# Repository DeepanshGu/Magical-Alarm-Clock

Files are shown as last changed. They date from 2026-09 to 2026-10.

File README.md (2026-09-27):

clockfrontview


# Magical Alarm Clock

A custom-built alarm clock featuring an ST7789 display, XIAO ESP32-C3 microcontroller, 
4 physical buttons, and a buzzer — designed from scratch as part of Hack Club's 
[BLARE](https://blare.hackclub.com/) program.

Built entirely with KiCad (schematic + PCB), Fusion 360 (enclosure), and Arduino IDE (firmware).

## Features

- Real-time clock display on a 284x76 ST7789 TFT screen
- Set the current time manually using onboard buttons (fully offline — no WiFi/NTP required)
- Set, enable, and disable a daily alarm
- Buzzer sounds when the alarm triggers, silenced with a button press
- Fully custom 2-layer PCB — no breadboard or dev-kit shield required
- 3D-printable enclosure designed in Fusion 360

## Hardware

| Component | Notes |
|---|---|
| Seeed XIAO ESP32-C3 | Main microcontroller |
| ST7789 TFT Display | 284x76 resolution (unusual — not the standard 240x320) |
| 4x Push Buttons | Mode / Increment / Decrement / Alarm toggle |
| Buzzer | Alarm sound output |
| Custom PCB | 2-layer, designed in KiCad |

## Bill of Materials

| Part | Qty | Notes |
|---|---|---|
| Seeed XIAO ESP32-C3 | 1 | Main microcontroller |
| ST7789 TFT Display (284x76) | 1 | Non-standard resolution |
| Push Button Switch | 4 | Mode / Increment / Decrement / Alarm |
| Buzzer | 1 | Alarm sound |
| Custom PCB | 1 | See /gerber and drillfiles folder |
| M3 Heat-set Inserts | 4 | For top plate mounting |
| M3 Screws | 4 | Pairs with heat-set inserts |

## Repository Structure

## Building the PCB

1. Open the KiCad project files in the `/pcb` folder.
2. Gerber and drill files are included for direct upload to a fabrication service (e.g. JLCPCB).
3. Board is a standard 2-layer FR-4 PCB.
   clockpcb

## Firmware Setup

1. Install [Arduino IDE](https://www.arduino.cc/en/software).
2. Add ESP32 board support via Boards Manager.
3. Install these libraries via Library Manager:
   - `Adafruit ST7735 and ST7789`
   - `Adafruit GFX`
4. Open `/firmware/magical_alarm_clock.ino`.
5. Update the GPIO pin definitions at the top of the file to match your wiring.
6. Select **XIAO_ESP32C3** as the board, choose the correct COM port, and upload.

## Enclosure

The case was designed in Fusion 360 around the PCB and display's real dimensions, 
with support posts for heat-set inserts and a cutout for the display and buttons. 
STEP files are available in `/enclosure`.

## Credits

- Built following the [BLARE](https://blare.hackclub.com/) guide by Liam Newbill, part of Hack Club's Stardance program.
- Designed and built by [Deepansh Gupta](https://github.com/DeepanshGu).

## License

*No license added yet.*

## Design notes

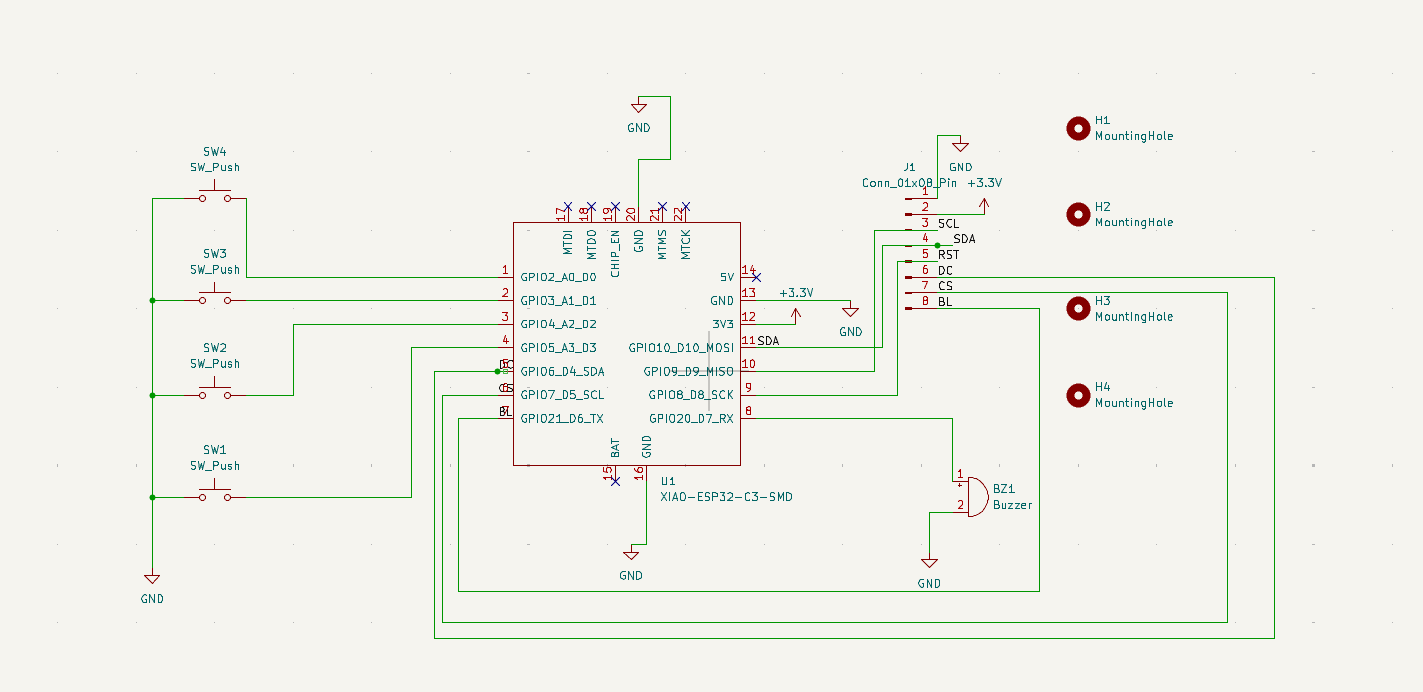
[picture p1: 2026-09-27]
images/clockschematic.png

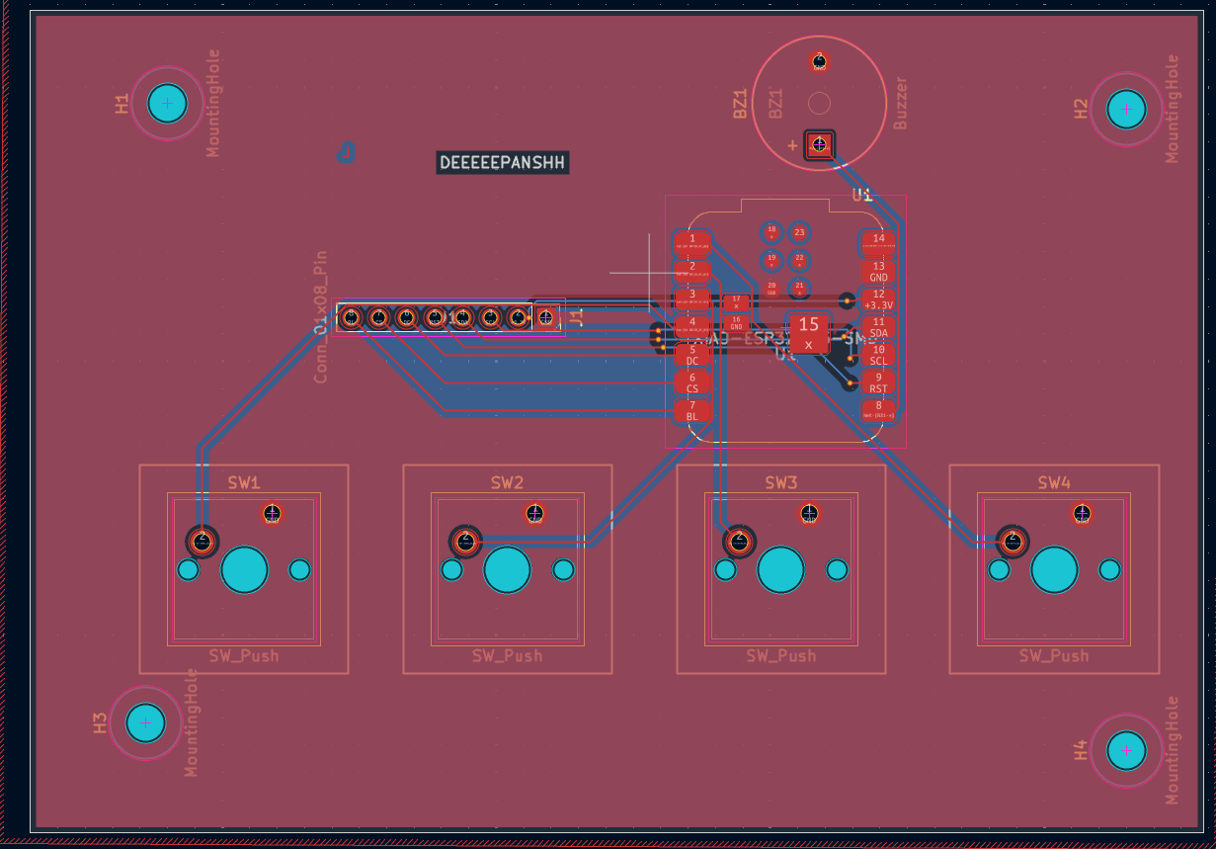
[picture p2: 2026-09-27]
images/clockpcb.png

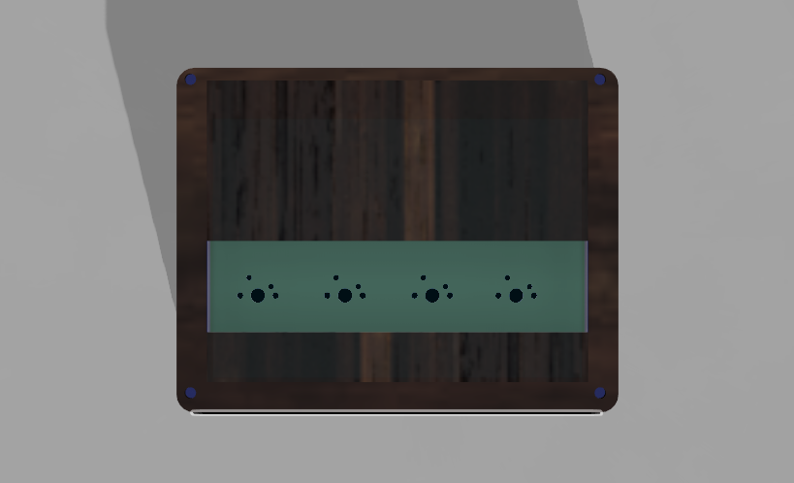
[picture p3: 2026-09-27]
images/clocktopview.png

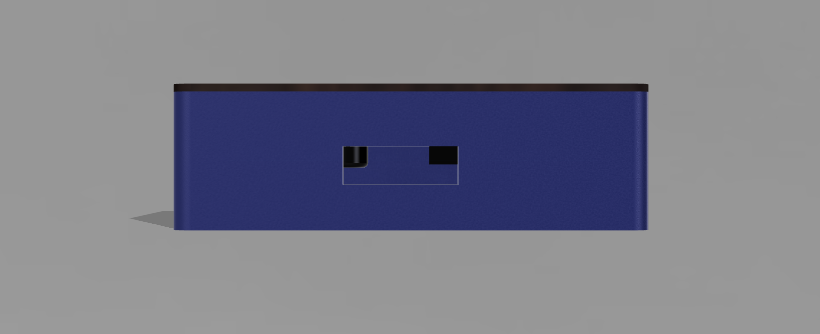
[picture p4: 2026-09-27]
images/clockbackview.png

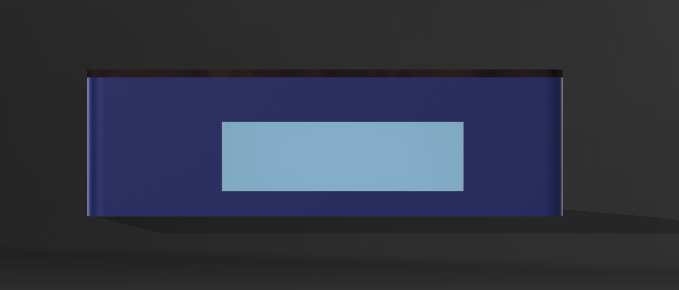
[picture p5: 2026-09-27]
images/clockfrontview.png

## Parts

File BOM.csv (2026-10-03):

Part | Qty | Unit Price (USD) | Link | Notes
Seeed XIAO ESP32-C3 | 1 | $5.49 | https://www.seeedstudio.com/Seeed-XIAO-ESP32C3-p-5431.html | Main microcontroller
2.25" TFT 76x284 SPI Display (ST7789P3) | 1 | $2.50 | https://www.buydisplay.com/chinese/2-25-inch-tft-serial-spi-76x284-lcd-display-module-w-st7789p3 | Non-standard resolution match
Tactile Push Button Switch 6x6mm (pack of 20) | 1 | $2.50 | https://www.adafruit.com/product/367 | Only 4 needed per clock; pack covers spares
5V Piezo Buzzer | 1 | $0.95 | https://www.adafruit.com/products/1536 | Breadboard-friendly; no driver circuit needed
M3 Brass Heat-Set Inserts (pack of 50) | 1 | $5.95 | https://www.adafruit.com/product/4256 | Only 4 needed per clock; pack covers spares
M3 Screws (6-8mm length) | 4 | ~$0.10 each |  | Widely available individually at any hardware/electronics store
Custom PCB | 1 | ~$8.20 (for 5 boards) | See /pcb/gerber-files.zip | JLCPCB quote for 2-layer 75x107mm board

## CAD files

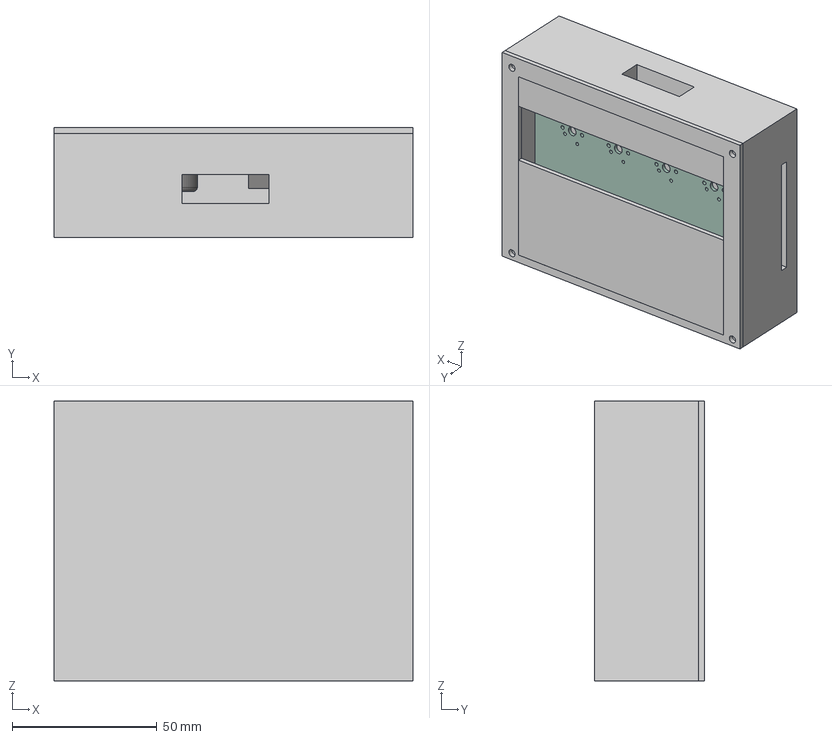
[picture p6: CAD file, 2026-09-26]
enclosure/Magical Clock.step
124.0 x 38.0 x 96.7 mm
Buzzer_12x95RM76
PinSocket_1x08_P2.54mm_Vertical_1
uhm4D89_PCB
8 pin header v1_1
8 pin header v1_1_1
8 pin header v1_1_2
8 pin header v1_1_3
8 pin header v1_1_4
8 pin header v1_1_5
8 pin header v1_1_6
8 pin header v1_1_7
8 pin header v1_1_8

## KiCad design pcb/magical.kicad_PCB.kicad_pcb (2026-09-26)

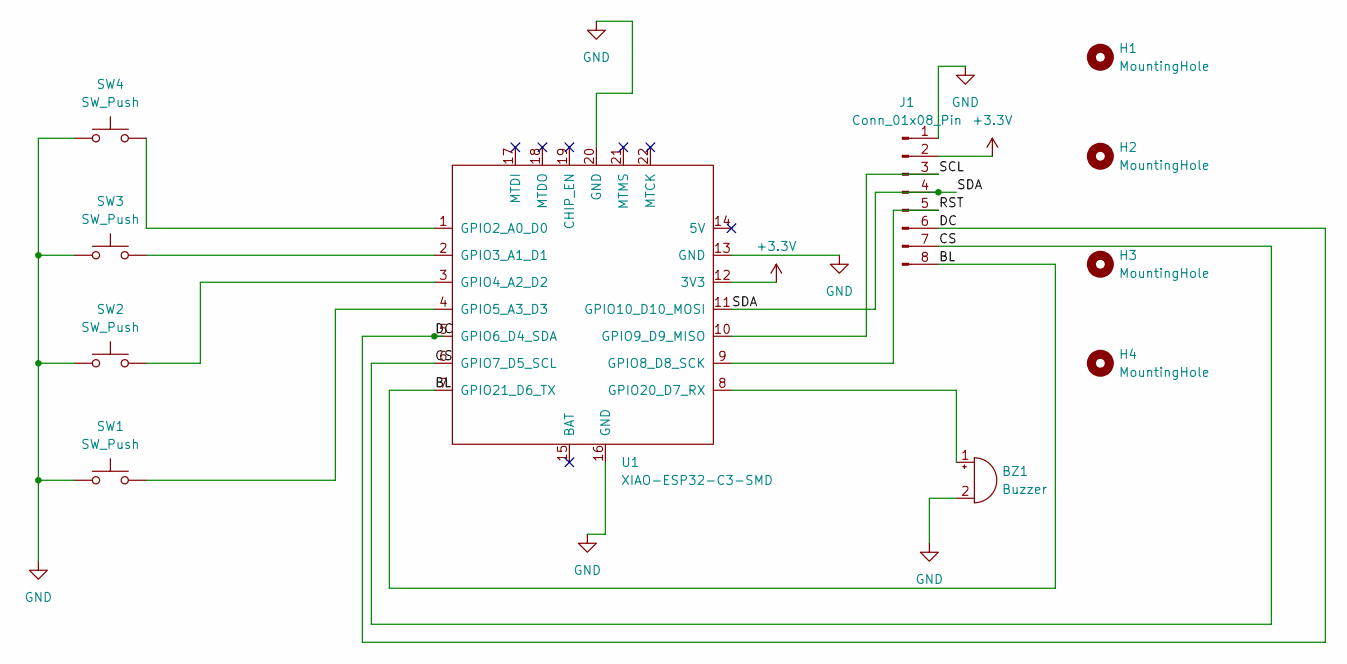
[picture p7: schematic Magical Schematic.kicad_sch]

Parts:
BZ1: Buzzer; Buzzer_12x9.5RM7.6
H1, H2, H3, H4: MountingHole; MountingHole_3.2mm_M3
J1: Conn_01x08_Pin; PinSocket_1x08_P2.54mm_Vertical
SW1, SW2, SW3, SW4: SW_Push; SW_Cherry_MX_1.00u_PCB
U1: XIAO-ESP32-C3-SMD; MCU_Seeed_ESP32C3

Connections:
+3.3V: J1.2, U1.12 (3V3)
/BL: J1.8, U1.7 (GPIO21_D6_TX)
/CS: J1.7, U1.6 (GPIO7_D5_SCL)
/DC: J1.6, U1.5 (GPIO6_D4_SDA)
/RST: J1.5, U1.9 (GPIO8_D8_SCK)
/SCL: J1.3, U1.10 (GPIO9_D9_MISO)
/SDA: J1.4, U1.11 (GPIO10_D10_MOSI)
GND: BZ1.2 (-), J1.1, SW1.1, SW2.1, SW3.1, SW4.1, U1.13 (GND), U1.16 (GND), U1.20 (GND)
unnamed: BZ1.1 (+), U1.8 (GPIO20_D7_RX)
unnamed: SW4.2, U1.1 (GPIO2_A0_D0)
unnamed: SW3.2, U1.2 (GPIO3_A1_D1)
unnamed: SW2.2, U1.3 (GPIO4_A2_D2)
unnamed: SW1.2, U1.4 (GPIO5_A3_D3)

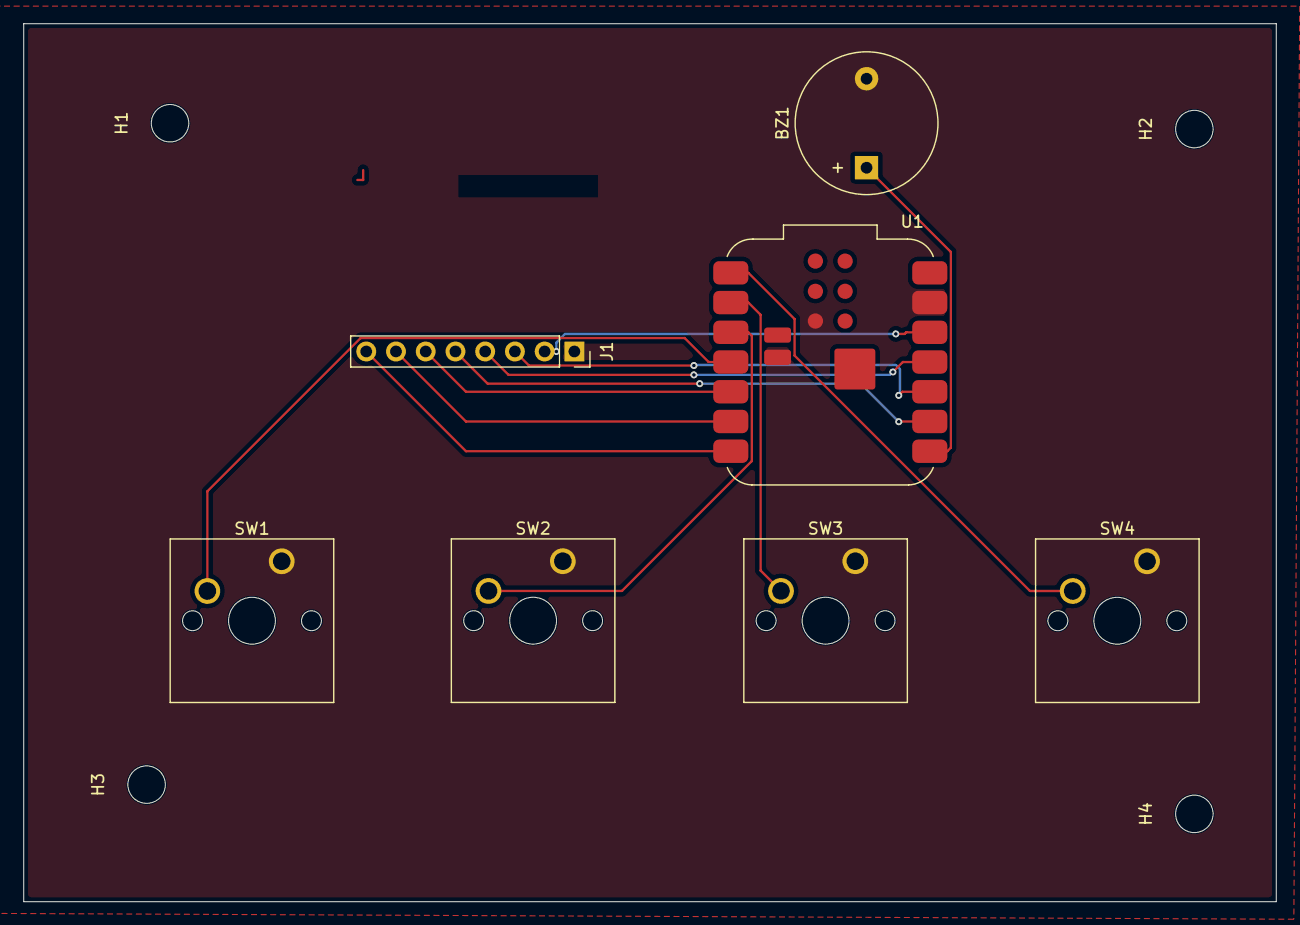
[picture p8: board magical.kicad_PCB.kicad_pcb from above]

Board: 2 copper layers, 107.0 x 75.0 mm, 11 parts (0 on the bottom side), 13 nets.

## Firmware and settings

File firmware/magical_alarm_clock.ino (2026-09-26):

#include <Adafruit_GFX.h>
#include <Adafruit_ST7789.h>
#include <SPI.h>

#define TFT_SCLK 10
#define TFT_MOSI 11
#define TFT_RST  9
#define TFT_DC   5
#define TFT_CS   6
#define TFT_BL   7

// --- FILL THESE IN with your actual GPIO numbers ---
#define BTN_MODE  4   // cycles through modes
#define BTN_INC   3   // increases the value being set / (+)
#define BTN_DEC   2   // decreases the value being set / (-)
#define BTN_ALARM 1   // toggles alarm on/off, or silences a ringing alarm
#define BUZZER_PIN 8  // your buzzer's signal pin
// ----------------------------------------------------

class Custom_ST7789 : public Adafruit_ST7789 {
  public:
    Custom_ST7789(int8_t cs, int8_t dc, int8_t mosi, int8_t sclk, int8_t rst)
      : Adafruit_ST7789(cs, dc, mosi, sclk, rst) {}
    void setOffsets(int8_t col, int8_t row) {
      setColRowStart(col, row);
    }
};

Custom_ST7789 tft = Custom_ST7789(TFT_CS, TFT_DC, TFT_MOSI, TFT_SCLK, TFT_RST);

// --- Clock state ---
int hours = 12;
int minutes = 0;
int seconds = 0;
unsigned long lastSecondTick = 0;

// --- Alarm state ---
int alarmHour = 7;
int alarmMinute = 0;
bool alarmEnabled = false;
bool alarmRinging = false;

// --- Modes ---
enum Mode { NORMAL, SET_HOUR, SET_MINUTE, SET_ALARM_HOUR, SET_ALARM_MINUTE };
Mode currentMode = NORMAL;

// --- Button edge-detection state ---
bool lastModeState  = HIGH;
bool lastIncState   = HIGH;
bool lastDecState   = HIGH;
bool lastAlarmState = HIGH;
  
void setup() {
Serial.begin(115200);

  pinMode(TFT_BL, OUTPUT);
  digitalWrite(TFT_BL, LOW);   // turns backlight ON

  pinMode(BTN_MODE, INPUT_PULLUP);
  pinMode(BTN_INC, INPUT_PULLUP);
  pinMode(BTN_DEC, INPUT_PULLUP);
  pinMode(BTN_ALARM, INPUT_PULLUP);
  pinMode(BUZZER_PIN, OUTPUT);
  digitalWrite(BUZZER_PIN, LOW);

  tft.init(76, 284);
  tft.setOffsets(82, 18);
  tft.invertDisplay(false);
  tft.setRotation(1);
  tft.fillScreen(ST77XX_BLACK);
  tft.setTextColor(ST77XX_WHITE);
  Serial.println("TFT Initialized!");

  lastSecondTick = millis();
}

void loop() {
// --- Advance the clock, only while not setting something ---
  if (currentMode == NORMAL && millis() - lastSecondTick >= 1000) {
    lastSecondTick = millis();
    seconds++;
    if (seconds >= 60) { seconds = 0; minutes++; }
    if (minutes >= 60) { minutes = 0; hours++; }
    if (hours >= 24) { hours = 0; }

    // Check if it's time to ring
    if (alarmEnabled && !alarmRinging && hours == alarmHour && minutes == alarmMinute && seconds == 0) {
      alarmRinging = true;
    }
  }

  // --- Ring the buzzer while alarm is active ---
  if (alarmRinging) {
    digitalWrite(BUZZER_PIN, (millis() / 300) % 2); // simple on/off beep pattern
  } else {
    digitalWrite(BUZZER_PIN, LOW);
  }

  // --- MODE button: cycle through modes ---
  bool modeState = digitalRead(BTN_MODE);
  if (modeState == LOW && lastModeState == HIGH) {
    switch (currentMode) {
      case NORMAL:          currentMode = SET_HOUR; break;
      case SET_HOUR:        currentMode = SET_MINUTE; break;
      case SET_MINUTE:      currentMode = SET_ALARM_HOUR; break;
      case SET_ALARM_HOUR:  currentMode = SET_ALARM_MINUTE; break;
      case SET_ALARM_MINUTE:currentMode = NORMAL; break;
    }
    delay(150); // debounce
  }
  lastModeState = modeState;

  // --- INC (+) button ---
  bool incState = digitalRead(BTN_INC);
  if (incState == LOW && lastIncState == HIGH) {
    if (currentMode == SET_HOUR)          hours = (hours + 1) % 24;
    else if (currentMode == SET_MINUTE)   { minutes = (minutes + 1) % 60; seconds = 0; }
    else if (currentMode == SET_ALARM_HOUR)   alarmHour = (alarmHour + 1) % 24;
    else if (currentMode == SET_ALARM_MINUTE) alarmMinute = (alarmMinute + 1) % 60;
    delay(150);
  }
  lastIncState = incState;

  // --- DEC (-) button ---
  bool decState = digitalRead(BTN_DEC);
  if (decState == LOW && lastDecState == HIGH) {
    if (currentMode == SET_HOUR)          hours = (hours + 23) % 24;
    else if (currentMode == SET_MINUTE)   { minutes = (minutes + 59) % 60; seconds = 0; }
    else if (currentMode == SET_ALARM_HOUR)   alarmHour = (alarmHour + 23) % 24;
    else if (currentMode == SET_ALARM_MINUTE) alarmMinute = (alarmMinute + 59) % 60;
    delay(150);
  }
  lastDecState = decState;

  // --- ALARM button: silence if ringing, else toggle on/off ---
  bool alarmState = digitalRead(BTN_ALARM);
  if (alarmState == LOW && lastAlarmState == HIGH) {
    if (alarmRinging) {
      alarmRinging = false; // silence it
    } else {
      alarmEnabled = !alarmEnabled; // toggle armed/disarmed
    }
    delay(150);
  }
  lastAlarmState = alarmState;

  // --- Draw the screen ---
  tft.fillScreen(ST77XX_BLACK);
  tft.setCursor(0, 0);
  tft.setTextSize(4);

  char timeStr[9];
  sprintf(timeStr, "%02d:%02d:%02d", hours, minutes, seconds);
  tft.print(timeStr);

  tft.setTextSize(2);
  tft.setCursor(0, 45);

  switch (currentMode) {
    case SET_HOUR:         tft.print("SET HOUR"); break;
    case SET_MINUTE:       tft.print("SET MIN"); break;
    case SET_ALARM_HOUR:   tft.print("ALARM HOUR"); break;
    case SET_ALARM_MINUTE: tft.print("ALARM MIN"); break;
    default: break;
  }

  tft.setCursor(0, 62);
  char alarmStr[20];
  sprintf(alarmStr, "AL %02d:%02d %s", alarmHour, alarmMinute, alarmEnabled ? "ON" : "OFF");
  tft.print(alarmStr);

  if (alarmRinging) {
    tft.setCursor(150, 45);
    tft.print("RING!");
  }

  delay(80);

}

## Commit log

2026-10-01 Rename Magical Schematic.kicad_sch to schematic/Magical Schematic.kicad_sch
    [Magical Schematic.kicad_sch]
2026-10-01 Rename magical clock.kicad_pro to pcb/magical clock.kicad_pro
2026-10-01 Rename gerber and drillfiles/uhm alarm clock-B_Cu.gbr to gerber and drillfiles/pcb/uhm alarm clock-B_Cu.gbr
    [uhm alarm clock-B_Cu.gbr]
2026-10-01 Rename gerber and drillfiles/uhm alarm clock-B_Mask.gbr to gerber and drillfiles/pcb/uhm alarm clock-B_Mask.gbr
    [uhm alarm clock-B_Mask.gbr]
2026-10-01 Rename gerber and drillfiles/uhm alarm clock-B_Paste.gbr to gerber and drillfiles/pcb/uhm alarm clock-B_Paste.gbr
    [uhm alarm clock-B_Paste.gbr]
2026-10-01 Rename gerber and drillfiles/uhm alarm clock.kicad_prl to gerber and drillfiles/pcb/uhm alarm clock.kicad_prl
2026-10-01 Rename gerber and drillfiles/uhm alarm clock-job.zip to gerber and drillfiles/pcb/uhm alarm clock-job.zip
2026-10-01 Rename gerber and drillfiles/uhm alarm clock-job.gbrjob to gerber and drillfiles/pcb/uhm alarm clock-job.gbrjob
    [uhm alarm clock-job.gbrjob]
2026-10-01 Rename gerber and drillfiles/uhm alarm clock-PTH.drl to gerber and drillfiles/pcb/uhm alarm clock-PTH.drl
    [uhm alarm clock-PTH.drl]
2026-10-01 Rename gerber and drillfiles/uhm alarm clock-NPTH.drl to gerber and drillfiles/pcb/uhm alarm clock-NPTH.drl
    [uhm alarm clock-NPTH.drl]
2026-10-01 Rename gerber and drillfiles/uhm alarm clock-F_Silkscreen.gbr to gerber and drillfiles/pcb/uhm alarm clock-F_Silkscreen.gbr
    [uhm alarm clock-F_Silkscreen.gbr]
2026-10-01 Rename gerber and drillfiles/uhm alarm clock-F_Paste.gbr to gerber and drillfiles/pcb/uhm alarm clock-F_Paste.gbr
    [uhm alarm clock-F_Paste.gbr]
2026-10-01 Rename gerber and drillfiles/uhm alarm clock-F_Mask.gbr to gerber and drillfiles/pcb/uhm alarm clock-F_Mask.gbr
    [uhm alarm clock-F_Mask.gbr]
2026-10-01 Rename gerber and drillfiles/uhm alarm clock-F_Cu.gbr to gerber and drillfiles/pcb/uhm alarm clock-F_Cu.gbr
    [uhm alarm clock-F_Cu.gbr]
2026-10-01 Rename gerber and drillfiles/uhm alarm clock-Edge_Cuts.gbr to gerber and drillfiles/pcb/uhm alarm clock-Edge_Cuts.gbr
    [uhm alarm clock-Edge_Cuts.gbr]
2026-10-01 Rename gerber and drillfiles/uhm alarm clock-B_Silkscreen.gbr to gerber and drillfiles/pcb/uhm alarm clock-B_Silkscreen.gbr
    [uhm alarm clock-B_Silkscreen.gbr]
2026-10-01 Rename Magical Clock.step to enclosure/Magical Clock.step
    [Magical Clock.step]
2026-10-01 Rename magicalclock gerber and drill files.zip to pcb/gerber-files.zip
